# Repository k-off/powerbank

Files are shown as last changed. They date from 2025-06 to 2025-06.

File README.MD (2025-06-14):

# PowerBank

Minimal DIY power bank with USB-C and fast charging.

## Overview

This minimal DIY power bank features a custom-designed case created in Fusion 360 to securely hold four 18650 lithium-ion cells, providing a robust and compact power source. The enclosure is tailored to fit the battery pack and the custom PCB, ensuring a neat and durable assembly. The PCB, designed in KiCad, incorporates the IP2312 charging IC for safe and efficient battery charging and the Texas Instruments TPS61022 boost converter to step up the battery voltage to a stable 5 V output. Both the USB-C input and output ports support up to 3A current, enabling fast charging and discharging capabilities suitable for modern devices.

The TPS61022 boost converter is a high-efficiency synchronous step-up converter capable of delivering 5 V at 3 A with an input voltage range from 0.5 V to 5.5 V, making it ideal for single-cell lithium-ion battery applications. It operates at a high switching frequency (up to 1 MHz) for low ripple and efficient power conversion, and includes protections such as overvoltage, thermal shutdown, and short-circuit protection.

The IP2312 charging IC manages the charging process of the 18650 cells, ensuring battery safety and longevity.

The power bank includes simple charge indicators showing charging in process and completion, though it currently lacks device charging or battery state indicators, maintaining a minimalist design focused on core functionality. This DIY power bank is ideal for enthusiasts seeking a custom, efficient, and compact portable power solution.

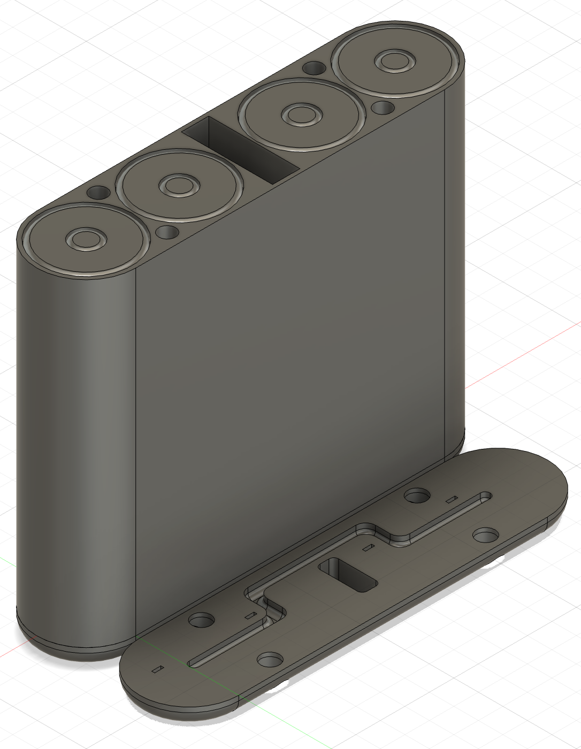
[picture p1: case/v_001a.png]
case


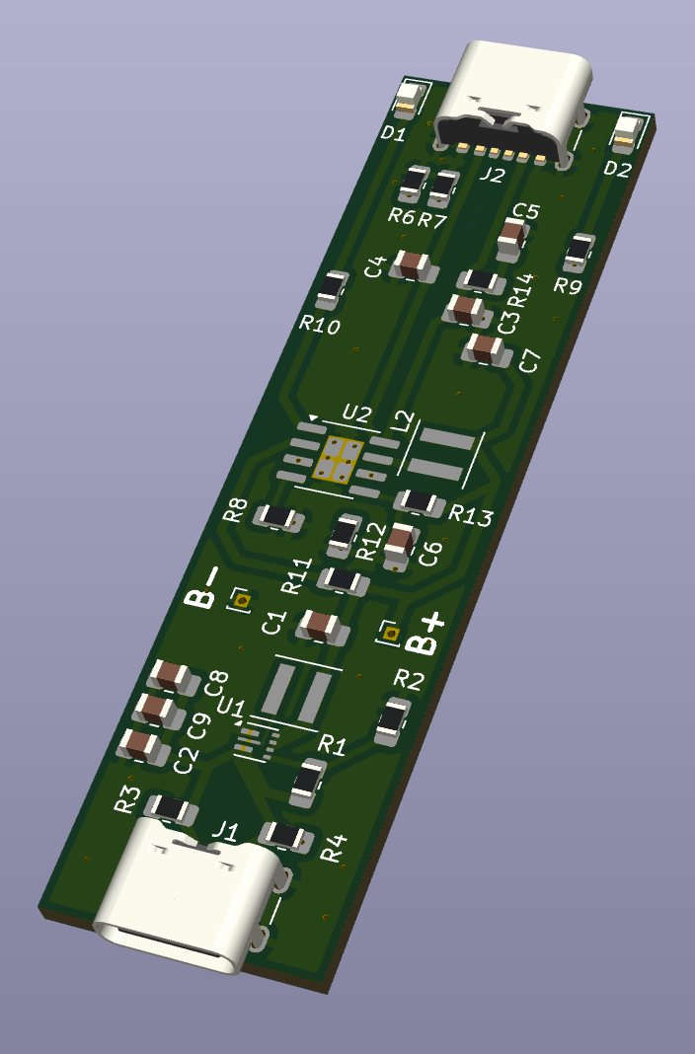
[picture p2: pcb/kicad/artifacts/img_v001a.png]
pcb


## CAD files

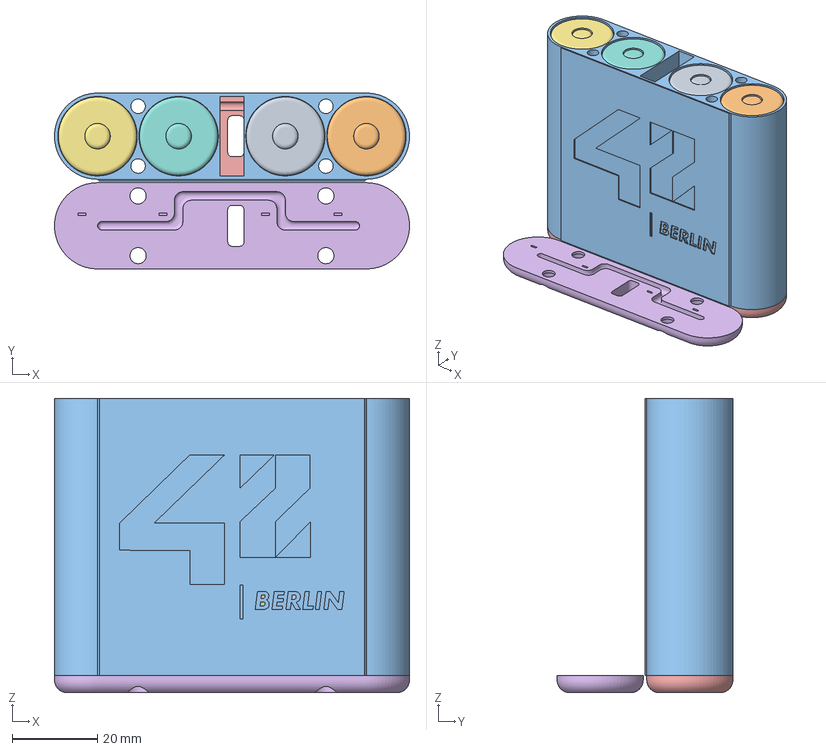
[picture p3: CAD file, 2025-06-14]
case/v_001a.3mf
83.2 x 41.2 x 69.0 mm
cap_in
cap_out
cell1
cell2
cell3
cell4
cell_holder

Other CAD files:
case/v_0001a.stl
case/v_001a.f3d

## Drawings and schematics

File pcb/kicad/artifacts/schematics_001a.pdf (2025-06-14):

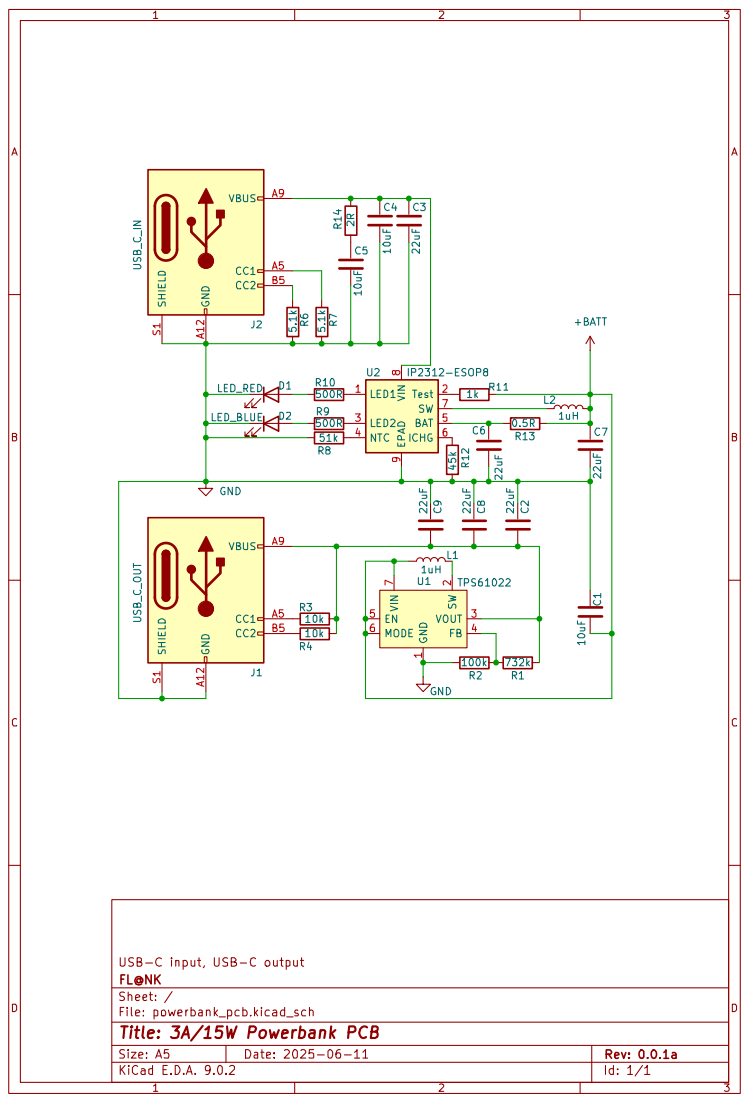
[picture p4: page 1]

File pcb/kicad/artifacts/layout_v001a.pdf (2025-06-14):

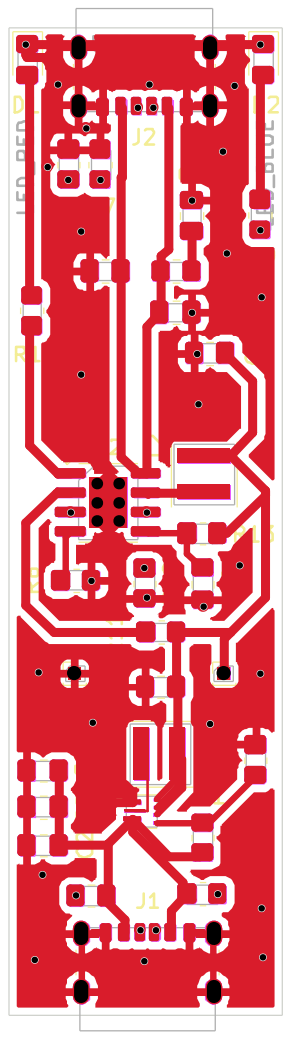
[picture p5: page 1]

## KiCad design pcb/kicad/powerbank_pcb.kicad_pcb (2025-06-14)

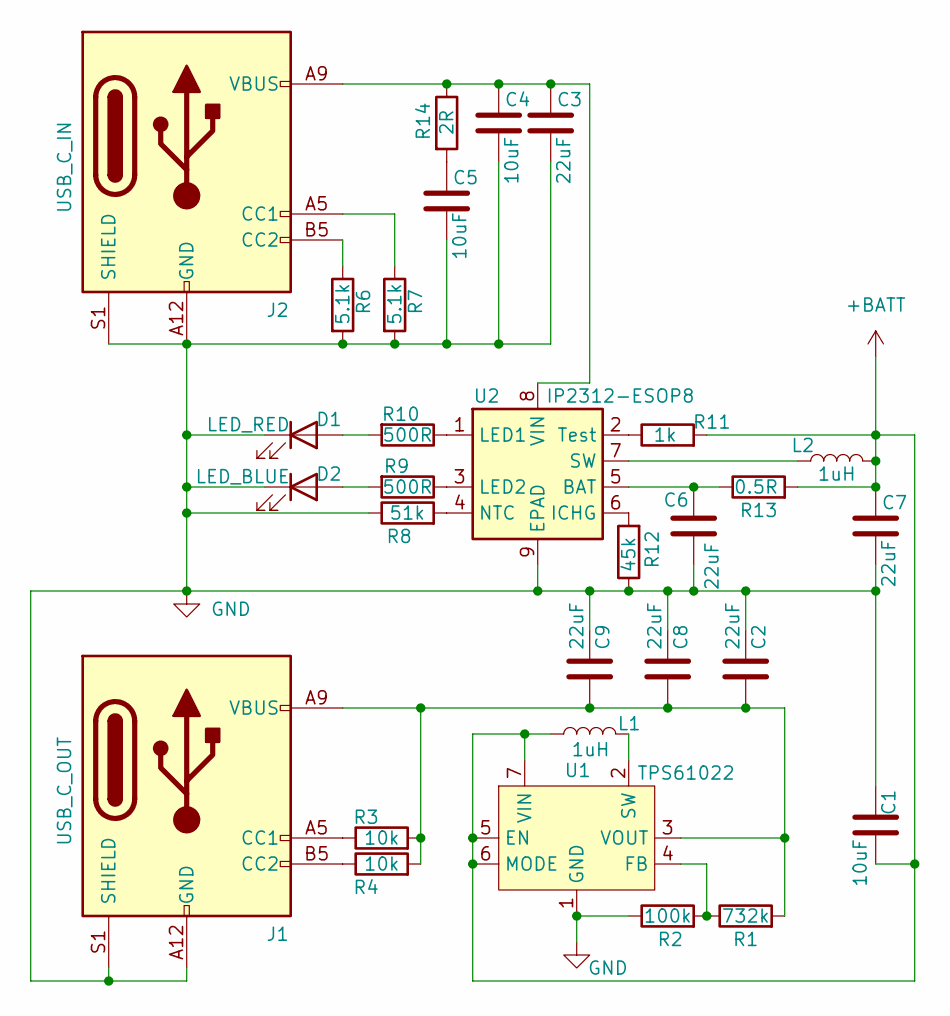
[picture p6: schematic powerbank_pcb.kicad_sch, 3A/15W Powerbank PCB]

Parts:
C1, C4, C5: 10uF; C_0805_2012Metric_Pad1.18x1.45mm_HandSolder
C2: 22uF
C3, C6, C7, C8, C9: 22uF; C_0805_2012Metric_Pad1.18x1.45mm_HandSolder
D1: LED_RED; LED_0805_2012Metric_Pad1.15x1.40mm_HandSolder
D2: LED_BLUE; LED_0805_2012Metric_Pad1.15x1.40mm_HandSolder
J1: USB_C_OUT; USB_C_Receptacle_GCT_USB4125-xx-x_6P_TopMnt_Horizontal
J2: USB_C_IN; USB_C_Receptacle_GCT_USB4125-xx-x_6P_TopMnt_Horizontal
L1, L2: 1uH; L_Coilcraft_XxL4030
R1: 732k; R_0805_2012Metric_Pad1.20x1.40mm_HandSolder
R2: 100k; R_0805_2012Metric_Pad1.20x1.40mm_HandSolder
R3, R4: 10k; R_0805_2012Metric_Pad1.20x1.40mm_HandSolder
R6, R7: 5.1k; R_0805_2012Metric_Pad1.20x1.40mm_HandSolder
R8: 51k; R_0805_2012Metric_Pad1.20x1.40mm_HandSolder
R9, R10: 500R; R_0805_2012Metric_Pad1.20x1.40mm_HandSolder
R11: 1k; R_0805_2012Metric_Pad1.20x1.40mm_HandSolder
R12: 45k; R_0805_2012Metric_Pad1.20x1.40mm_HandSolder
R13: 0.5R; R_0805_2012Metric_Pad1.20x1.40mm_HandSolder
R14: 2R; R_0805_2012Metric_Pad1.20x1.40mm_HandSolder
U1: TPS61022; Texas_RWU0007A_VQFN-7_2x2mm_P0.5mm
U2: IP2312-ESOP8; SOIC-8-1EP_3.9x4.9mm_P1.27mm_EP2.41x3.3mm_ThermalVias

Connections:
+BATT: C1.1, C7.1, L1.1, L2.2, R11.2, R13.2, U1.5 (EN), U1.6 (MODE), U1.7 (VIN)
GND: C1.2, C2.1, C3.2, C4.2, C5.2, C6.2, C7.2, C8.1, C9.1, D1.1 (K), D2.1 (K), J1.A12 (GND), J1.B12 (GND), J1.S1 (SHIELD), J2.A12 (GND), J2.B12 (GND), J2.S1 (SHIELD), R2.1, R6.2, R7.2, R8.1, R12.1, U1.1 (GND), U2.9 (EPAD)
unnamed: C5.1, R14.2
unnamed: D1.2 (A), R10.2
unnamed: D2.2 (A), R9.2
unnamed: J1.A5 (CC1), R3.1
unnamed: J1.B5 (CC2), R4.1
unnamed: J2.A5 (CC1), R7.1
unnamed: J2.B5 (CC2), R6.1
unnamed: R1.1, R2.2, U1.4 (FB)
unnamed: L1.2, U1.2 (SW)
unnamed: C2.2, C8.2, C9.2, J1.A9 (VBUS), J1.B9 (VBUS), R1.2, R3.2, R4.2, U1.3 (VOUT)
unnamed: C6.1, R13.1, U2.5 (BAT)
unnamed: R12.2, U2.6 (ICHG)
unnamed: R10.1, U2.1 (LED1)
unnamed: R9.1, U2.3 (LED2)
unnamed: R8.2, U2.4 (NTC)
unnamed: L2.1, U2.7 (SW)
unnamed: R11.1, U2.2 (Test)
unnamed: C3.1, C4.1, J2.A9 (VBUS), J2.B9 (VBUS), R14.1, U2.8 (VIN)

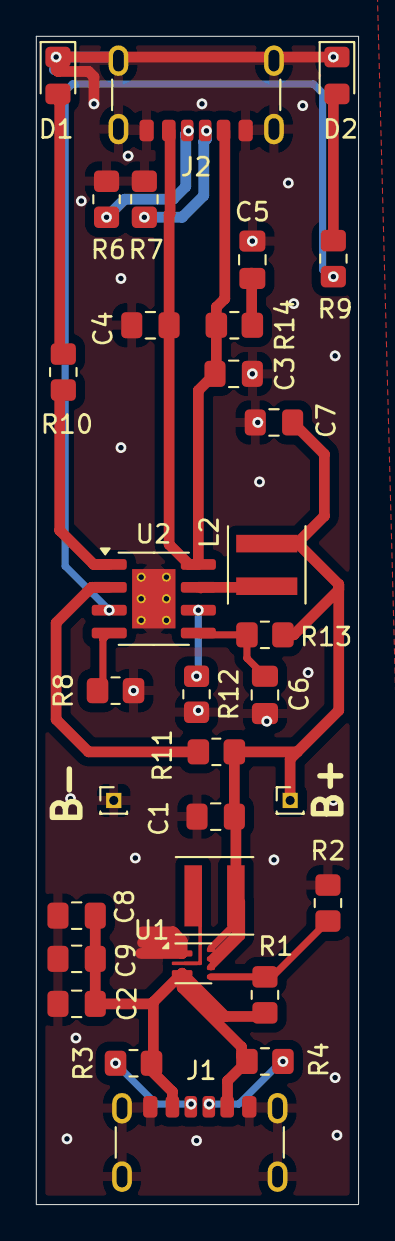
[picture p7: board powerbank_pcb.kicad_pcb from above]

Board: 2 copper layers, 17.9 x 64.9 mm, 30 parts (0 on the bottom side), 20 nets.
